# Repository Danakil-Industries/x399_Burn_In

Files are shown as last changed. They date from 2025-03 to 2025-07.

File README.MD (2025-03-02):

This project is about developing a low cost burn-in station for LM399s and ADR1399s in TO-46 packages.

Goals:
	1. Reference-supply rails seperate from, or at least derived from, heater supply rail.
	2. Able to burn-in at least 4 Vrefs simultaneously per unit
	3. All components at least 0603 or larger for ease of assembly
		*Preferrably 0805 or larger
	4. Socketed Vrefs
		*Probably use 2mm 2x2 F headers.
	5. Low cost
		*Possibly have multiple variants, enabling people to not need to spend more on functions they might not want to spend money on
			*Make bare-bones design
	Optional 1 (abandoned): Have a resettable hour meter to keep track of how long the Vrefs have been burning in for
								*Would have increased cost too much. Maybe make as an accessory for the unit?
	Optional 2: Have LEDs for indicating that the heater and +15v rail are alive
	Optional 3: Hot-swapable X399s
					*Alternatively, have a way to safely load a Vref without powering down the whole unit
					*Might end up being too expensive
	Optional 4: LEDs showing if the voltage seen at the X399's Vref+ pin is too high(>≈7.5v), fine(≈7.5v>Vref>≈6.5v), or too low(<≈6.5v)
					*Yes, this range is WAY over the tolerances of the Vrefs. It is meant to indicate if something has gone seriously wrong.
	Optional 5: If Vref+ voltage is too high, shut down the current supply, go into an error state, and light an error LED.

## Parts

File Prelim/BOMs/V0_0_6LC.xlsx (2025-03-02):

X399 Burn In V0.0.6LC
 | WIP |  |  |  | $21.58
 | index | Designator | Value | PN | Cost | Comment | To Add?
 | 1 | AC-DC1 | 18V18W wall wart | 1939-2007-ND | $6.50 | Barrel Plug, 2.5mm I.D. x 5.5mm O.D. x 11.0mm | Y
 | 2 | J1 |  |  |  |  | Y
 | 3 | F1 | 1AF63V | C1F 1 | $0.34 | 1206 package | Y
 | 4 | VR1 | 18v varistor | BVR0805-14PFR | $0.40 |  | Y
 | 5 | D1 | 40V 2A schottky | SS2040LL_R1_00001 | $0.15 |  | Y
 | 6 | FB1 | 600Ω@100MHz | 2508056017Y2 | $0.10 |  | Y
 | 7 | C1 | 100nF 50V | CL31B104KBCNNNC | $0.10 | 1206 | N
 | 8 | C2 | 10uF 25V | CL31A106KAHNNNE | $0.15 | 1206 | N
 | 9 | DC-DC1 | 3.3v 500mA | R-78E3.3-0.5 | $3.30 |  | Y
 | 10 | L1 | 12uH 58mΩ 2.2A | ASPI-6045S-120M-T | $0.39 |  | Y
 | 11 | C3 | 10uF 25V | CL31A106KAHNNNE | $0.15 |  | N
 | 12 | C4 | 4.7uF | CL31B475KAHNNNE | $0.15 |  | Y
 | 13 | C5 | DNP | DNP | $0.00 | DNP
 | 14 | R1 | 1k | RMCF1206FT1K00 | $0.10 |  | N
 | 15 | C6 | 1uF 50v | CL21F105ZBFNNNG | $0.10 |  | N
 | 16 | U1 | Quad Op Amp | LM324ADR | $0.26 |  | Y
 | 17 | U2 | 78L15 | L78L15ACD13TR | $0.25 | 8-SOIC pkg | Y
 | 18 | C7 | 100nF 50V | CL31B104KBCNNNC | $0.10 |  | N
 | 19 | SW1 | Push Switch DPDT | MHPS2273 | $0.74 |  | Y
 | 20 | SW2 | Push Switch DPDT | MHPS2273 | $0.74 |  | Y
 | 21 | SW3 | Push Switch DPDT | MHPS2273 | $0.74 |  | Y
 | 22 | SW4 | Push Switch DPDT | MHPS2273 | $0.74 |  | Y
 | 23 | SW5 | Push Switch DPDT | MHPS2273 | $0.74 |  | Y
 | 24 | Q1 | 2222 | MMBT2222A-TP | $0.11 |  | Y
 | 25 | D2 | Green LED | 151031VS06000 | $0.15 |  | N
 | 26 | D3 | Green LED | 151031VS06000 | $0.15 |  | N
 | 27 | D4 | Green LED | 151031VS06000 | $0.15 |  | N
 | 28 | D5 | Green LED | 151031VS06000 | $0.15 |  | N
 | 29 | D6 | Green LED | 151031VS06000 | $0.15 |  | N
 | 30 | R2 | 100Ω 1% 1206 | RMCF1206FT100R | $0.10 |  | N
 | 31 | R3 | 100Ω 1% 1206 | RMCF1206FT100R | $0.10 |  | N
 | 32 | R4 | 100Ω 1% 1206 | RMCF1206FT100R | $0.10 |  | N
 | 33 | R5 | 100Ω 1% 1206 | RMCF1206FT100R | $0.10 |  | N
 | 34 | R6 | 100Ω 1% 1206 | RMCF1206FT100R | $0.10 |  | N
 | 35 | R7 | 100Ω 1% 1206 | RMCF1206FT100R | $0.10 |  | N
 | 36 | D7 | Dual Schottky | BAS40-05,215 | $0.10 | SOT-23 | Y
 | 37 | D8 | Dual Schottky | BAS40-05,215 | $0.10 | SOT-23 | Y
 | 38 | D9 | Dual Schottky | BAS40-05,215 | $0.10 | SOT-23 | Y
 | 39 | D10 | Dual Schottky | BAS40-05,215 | $0.10 | SOT-23 | Y
 | 40 | RN1 | 1k 1% 4 Element | CAY16-1001F4LF | $0.10 | 1206 | Y
 | 41 | RN2 | 1k 1% 4 Element | CAY16-1001F4LF | $0.10 | 1206 | Y
 | 42 | RN3 | 1k 1% 4 Element | CAY16-1001F4LF | $0.10 | 1206 | Y
 | 43 | RN4 | 1k 1% 4 Element | CAY16-1001F4LF | $0.10 | 1206 | Y
 | 44 | C8 | 1uF 50v | CL21F105ZBFNNNG | $0.10 |  | N
 | 45 | C9 | 1uF 50v | CL21F105ZBFNNNG | $0.10 |  | N
 | 46 | C10 | 1uF 50v | CL21F105ZBFNNNG | $0.10 |  | N
 | 47 | C11 | 1uF 50v | CL21F105ZBFNNNG | $0.10 |  | N
 | 48 | J2 | 2x2 2mm F Hdr | S5750-02-ND | $0.67 |  | Y
 | 49 | J3 | 2x2 2mm F Hdr | S5750-02-ND | $0.67 |  | Y
 | 50 | J4 | 2x2 2mm F Hdr | S5750-02-ND | $0.67 |  | Y
 | 51 | J5 | 2x2 2mm F Hdr | S5750-02-ND | $0.67 |  | Y

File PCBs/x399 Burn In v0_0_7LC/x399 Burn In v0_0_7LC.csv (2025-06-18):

Source: | E:\Github\x399 Burn In\x399_Burn_In\PCBs\x399 Burn In v0_0_7LC\x399 Burn In v0_0_7LC.kicad_sch
Date: | 6/16/2025 7:44:11 PM
Tool: | Eeschema 7.0.10
Generator: | E:\KICad\7.0\bin\scripting\plugins/bom_csv_grouped_by_value.py
Component Count: | 57
Collated Components:
Item | Qty | Reference(s) | Value | LibPart | Footprint | Datasheet | DNP | Breaking Capacity (A AC) | Breaking Capacity (A DC) | Color | Comment | Current (A) | Current Rating (A) | DCR | DCR (max) | Diameter | Distributor | Distributor PN | Drive Type | Energy (J) | For | Gain | Has Hole | Head Type | Height | I (max) | ID | Ic | If (mA) | Imax | Imax (DC) | Iout | Iout Max | MFG | MFG PN | Matching Ratio | Material | Mating Connector PN | Max ACV | Max DCV | Max Voltage | Melting I2T | Min ESR(mΩ) | Mounting Type | Name | Number of elements | OD | Pmax | Power | Power / element (mW) | Ratio Drift (PPM/°C) | Response Time | Schematic Only | Sim.Device | Sim.Pins | Sim.Type | Size | Surge Current (A) | Symbol
1 | 1 | AC-DC1 | 18V 1A 18W | Danakil_database:PSUs - Wall Wart/18V 1A 18W Wall Wart | Connectors:CUI_PJ-002B | https://globtek.secure.force.com/spec/?id=01t0c0000097CKB |  |  |  |  |  | 1 |  |  |  |  | Digikey | 1939-2007-ND |  |  |  |  |  |  |  |  |  |  |  |  |  |  |  | GlobTek, Inc. | WR9HH1000LCP-F(R6B) |  |  | PJ-002B |  |  |  |  |  |  | 18V 1A 18W Wall Wart |  |  |  |  |  |  |  |  |  |  |  |  |  | 0Dan_PSUs_WallWarts:WR9HH1000LCP-F(R6B)
2 | 2 | C1, C3 | 10u | Danakil_database:Capacitors - Unpolarized/10uF 25V 1206 X5R SMD MLCC | Capacitors_SMD:C_1206_3216Metric | https://mm.digikey.com/Volume0/opasdata/d220001/medias/docus/609/CL31A106KAHNNNE_SS.pdf |  |  |  |  |  |  |  |  |  |  | Digikey | 1276-1075-1-ND |  |  |  |  |  |  |  |  |  |  |  |  |  |  |  | Samsung Electro-Mechanics | CL31A106KAHNNNE |  |  |  |  |  |  |  |  | SMD | 10uF 25V 1206 X5R SMD MLCC |  |  |  |  |  |  |  |  |  |  |  | 1206 |  | 0Dan_Passives:C
3 | 2 | C2, C7 | 100n | Danakil_database:Capacitors - Unpolarized/100nF 50V 1206 X7R SMD MLCC | Capacitors_SMD:C_1206_3216Metric | https://mm.digikey.com/Volume0/opasdata/d220001/medias/docus/1256/CL31B104KBCNNNC_Spec.pdf |  |  |  |  |  |  |  |  |  |  | Digikey | 1276-1017-1-ND |  |  |  |  |  |  |  |  |  |  |  |  |  |  |  | Samsung Electro-Mechanics | CL31B104KBCNNNC |  |  |  |  |  |  |  |  | SMD | 100nF 50V 1206 X7R SMD MLCC |  |  |  |  |  |  |  |  |  |  |  | 1206 |  | 0Dan_Passives:C
4 | 2 | C4, C5 | 4.7u | Danakil_database:Capacitors - Unpolarized/4.7uF 25V 1206 X7R SMD MLCC | Capacitors_SMD:C_1206_3216Metric | https://mm.digikey.com/Volume0/opasdata/d220001/medias/docus/41/CL31B475KAHNNNE_Spec.pdf |  |  |  |  |  |  |  |  |  |  | Digikey | 1276-1055-1-ND |  |  |  |  |  |  |  |  |  |  |  |  |  |  |  | Samsung Electro-Mechanics | CL31B475KAHNNNE |  |  |  |  |  |  |  |  | SMD | 4.7uF 25V 1206 X7R SMD MLCC |  |  |  |  |  |  |  |  |  |  |  | 1206 |  | 0Dan_Passives:C
5 | 5 | C6, C8, C9, C10, C11 | 1u | Danakil_database:Capacitors - Unpolarized/1uF 50V 0805 Y5V SMD MLCC | Capacitors_SMD:C_0805_2012Metric | https://weblib.samsungsem.com/mlcc/mlcc-ec-data-sheet.do?partNumber=CL05Y105KP6VPN |  |  |  |  |  |  |  |  |  |  | Digikey | 1276-6495-1-ND |  |  |  |  |  |  |  |  |  |  |  |  |  |  |  | Samsung Electro-Mechanics | CL21F105ZBFNNNG |  |  |  |  |  |  |  |  | SMD | 1uF 50V 0805 Y5V SMD MLCC |  |  |  |  |  |  |  |  |  |  |  | 0805 |  | 0Dan_Passives:C
6 | 1 | D1 | Schottky 40V 2A SMD | Danakil_database:Discreet - Diodes - Schottky/Schottky 40V 2A SMD | Diodes:D_SOD-123F | https://www.panjit.com.tw/upload/datasheet/SS2040LL.pdf |  |  |  |  |  |  |  |  |  |  | Digikey | 3757-SS2040LL_R1_00001CT-ND |  |  |  |  |  |  |  | 2A |  |  |  |  |  |  |  | Panjit International Inc. | SS2040LL_R1_00001 |  |  |  |  |  |  |  |  | SMD | Schottky 40V 2A SMD |  |  |  |  |  |  |  |  |  | 1=K 2=A |  |  |  | 0Dan_Discreet:Diode_Schottky
7 | 5 | D2, D3, D4, D5, D6 | Green 3mm | Danakil_database:LEDs - Standard - Indicator - Through Hole/Green 3mm 560nm 2.2v 20mA | Discreet_TH:LED_3mm_wurth | https://www.we-online.com/components/products/datasheet/151031VS06000.pdf |  |  |  | Green |  |  |  |  |  |  | Digikey | 732-5008-ND |  |  |  |  |  |  |  |  |  |  | 20 |  |  |  |  | Würth Elektronik | 151031VS06000 |  |  |  |  |  |  |  |  |  | Green 3mm 560nm 2.2v 20mA |  |  |  |  |  |  |  |  |  |  |  | 3mm |  | 0Dan_Discreet:LED
8 | 4 | D7, D8, D9, D10 | Schottky 40V 0.12A SMD | Danakil_database:Discreet - Diodes - Schottky/Schottky 40V 0.12A SMD Dual CC | Discreet_SMD:SOT-23-3_1 | https://assets.nexperia.com/documents/data-sheet/BAS40-05.pdf |  |  |  |  | Dual CC |  |  |  |  |  | Digikey | 1727-4235-1-ND |  |  |  |  |  |  |  | 0.12A |  |  |  |  |  |  |  | Nexperia USA Inc. | BAS40-05,215 |  |  |  |  |  |  |  |  | SMD | Schottky 40V 0.12A SMD Dual CC |  |  |  |  |  |  |  |  |  |  |  |  |  | 0Dan_Discreet:Diode_Schottky_BAS40-05
9 | 1 | DC-DC1 | 5v 0.5A Buck | Danakil_database:PSUs - PCB Mount - DC-DC - Non-Isolated/Buck 7v-28v to 5v0.5A | DCDC_NonIso:R-78E-0.5 | https://recom-power.com/pdf/Innoline/R-78E-0.5.pdf |  |  |  |  |  |  |  |  |  |  | Digikey | 945-1648-5-ND |  |  |  |  |  |  |  |  |  |  |  |  |  | 0.5A |  | Recom Power | R-78E5.0-0.5 |  |  |  |  |  |  |  |  |  | Buck 7v-28v to 5v0.5A |  |  |  |  |  |  |  |  |  |  |  |  |  | 0Dan_PSUs:78xx Replacement
10 | 1 | F1 | 125VAC/63VDC 1A F | Danakil_database:Protection - Fuses/125VAC/63VDC 1A F SMD | Protection_Fuses:Fuse_1206 | https://www.belfuse.com/resources/datasheets/circuitprotection/ds-cp-c1f-series.pdf |  | 100 | 50 |  |  |  | 1 |  |  |  | Digikey | 5923-C1F1CT-ND |  |  |  |  |  |  |  |  |  |  |  |  |  |  |  | Bel Fuse Inc. | C1F 1 |  |  |  |  |  |  | 0.012 |  | SMD | 125VAC/63VDC 1A F SMD |  |  |  |  |  |  | F |  |  |  |  |  |  | 0Dan_Protection:Fuse
11 | 1 | FB1 | 600Ω@100MHz 0.1ΩDCR | Danakil_database:Inductors - Ferrite Bead/600Ω@100MHz 2A 0.1ΩDCR | Inductors_SMD:L_0805_2012Metric | https://fair-rite.com/product/chip-beads-2508056017y2/ |  |  |  |  |  |  |  |  | 0.1Ω |  | Digikey | 1934-1487-1-ND |  |  |  |  |  |  |  |  |  |  |  | 2A |  |  |  | Fair-Rite Products Corp. | 2508056017Y2 |  |  |  |  |  |  |  |  |  | 600Ω@100MHz 2A 0.1ΩDCR |  |  |  |  |  |  |  |  |  |  |  |  |  | 0Dan_Passives:FB
12 | 1 | J1 | 2.5mmID 5.5mmOD | Danakil_database:Connectors - Barrel Jack/2.5mmID 5.5mmOD | Connectors:CUI_PJ-002B | https://www.sameskydevices.com/product/resource/pj-002b.pdf |  |  |  |  |  |  |  |  |  |  | Digikey | CP-002B-ND |  |  |  |  |  |  |  |  | 2.5mm |  |  |  |  |  |  | Same Sky (Formerly CUI Devices) | PJ-002B |  |  |  |  |  |  |  |  |  | 2.5mmID 5.5mmOD |  | 5.5mm |  |  |  |  |  |  |  |  |  |  |  | 0Dan_Connectors:Barrel_Jack_Switch
13 | 1 | L1 | 12u | Danakil_database:Inductors/12uH 2.2A 58mΩ 20% NonStd SMD | Inductors_SMD:ASPI-6045S-120M-T | https://abracon.com/Magnetics/power/ASPI-6045S.pdf |  |  |  |  |  |  |  | 58m |  |  | Digikey | 535-ASPI-6045S-120M-TCT-ND |  |  |  |  |  |  |  |  |  |  |  |  |  |  |  | Abracon LLC | ASPI-6045S-120M-T |  |  |  |  |  |  |  |  | SMD | 12uH 2.2A 58mΩ 20% NonStd SMD |  |  |  |  |  |  |  |  |  |  |  | NonStd |  | 0Dan_Passives:L
14 | 1 | M1 | M3x0.5 0.3mm_tall | Danakil_database:Mechanical - Standoffs - SMD/M3x0.5 0.3mm_tall Elect_Conn | Mechanical_Standoffs_SMD:24939_ElecConn | https://www.keyelco.com/product-pdf.cfm?p=14826 |  |  |  |  | Elect_Conn |  |  |  |  |  | Digikey | 36-24939CT-ND |  |  |  |  |  |  | 0.3mm |  |  |  |  |  |  |  |  | Keystone Electronics | 24939 |  |  |  |  |  |  |  |  |  | M3x0.5 0.3mm_tall Elect_Conn |  |  |  |  |  |  |  |  |  |  |  |  |  | 0Dan_Mech_Standoffs:SMD_ElecConn
15 | 4 | M2, M3, M4, M5 | 9.5mm Black | Danakil_database:Mechanical - Feet/9.5mm_dia 5.4mm_height Black | Feet:BS22BL05X06RP | https://mm.digikey.com/Volume0/opasdata/d220001/medias/docus/699/Bumper_Brochure.pdf |  |  |  | Black |  |  |  |  |  | 9.5mm | Digikey | 2042-1050-ND |  |  |  |  |  |  | 5.4mm |  |  |  |  |  |  |  |  | Bumper Specialties Inc. | BS22BL05X06RP |  |  |  |  |  |  |  |  |  | 9.5mm_dia 5.4mm_height Black |  |  |  |  |  |  |  |  |  |  |  |  |  | 0Dan_Mech_Feet:Foot
16 | 1 | Q1 | 2222A | Danakil_database:Discreet - Transistors - BJT - NPN/2222A 40V-Vce 0.6A-Ic 0.35W 100-Bmin SMD | Discreet_SMD:SOT-23-3 | https://www.mccsemi.com/pdf/Products/MMBT2222A(SOT-23).pdf |  |  |  |  |  |  |  |  |  |  | Digikey | MMBT2222ATPMSCT-ND |  |  |  | 100 |  |  |  |  |  | 0.6A |  |  |  |  |  | MCC (Micro Commercial Components) | MMBT2222A-TP |  |  |  |  |  |  |  |  | SMD | 2222A 40V-Vce 0.6A-Ic 0.35W 100-Bmin SMD |  |  | 0.35W |  |  |  |  |  | NPN | 1=C 2=B 3=E | GUMMELPOON |  |  | 0Dan_Discreet:NPN
17 | 1 | R1 | 1k | Danakil_database:Resistors - Single - SMD/1kΩ 1% 1206 0.25w Thick Film 200ppm/°C Automotive | Resistors_SMD:R_1206_3216Metric | https://www.seielect.com/catalog/sei-rmcf_rmcp.pdf |  |  |  |  | Automotive |  |  |  |  |  | Digikey | RMCF1206FT1K00CT-ND |  |  |  |  |  |  |  |  |  |  |  |  |  |  |  | Stackpole Electronics Inc | RMCF1206FT1K00 |  |  |  |  |  |  |  |  |  | 1kΩ 1% 1206 0.25w Thick Film 200ppm/°C Automotive |  |  |  | 0.25 |  |  |  |  |  |  |  | 1206 |  | 0Dan_Passives:R_US
18 | 1 | R2 | 47k | Danakil_database:Resistors - Single - SMD/47kΩ 1% 1206 0.25w Thick Film 100ppm/°C Automotive | Resistors_SMD:R_1206_3216Metric | https://www.seielect.com/catalog/sei-rmcf_rmcp.pdf |  |  |  |  | Automotive |  |  |  |  |  | Digikey | RMCF1206FT47K0CT-ND |  |  |  |  |  |  |  |  |  |  |  |  |  |  |  | Stackpole Electronics Inc | RMCF1206FT47K0 |  |  |  |  |  |  |  |  |  | 47kΩ 1% 1206 0.25w Thick Film 100ppm/°C Automotive |  |  |  | 0.25 |  |  |  |  |  |  |  | 1206 |  | 0Dan_Passives:R_US
19 | 5 | R3, R4, R5, R6, R7 | 330 | Danakil_database:Resistors - Single - SMD/330Ω 1% 1206 0.25w Thick Film 100ppm/°C Automotive | Resistors_SMD:R_1206_3216Metric | https://www.seielect.com/catalog/sei-rmcf_rmcp.pdf |  |  |  |  | Automotive |  |  |  |  |  | Digikey | RMCF1206FT330RCT-ND |  |  |  |  |  |  |  |  |  |  |  |  |  |  |  | Stackpole Electronics Inc | RMCF1206FT330R |  |  |  |  |  |  |  |  |  | 330Ω 1% 1206 0.25w Thick Film 100ppm/°C Automotive |  |  |  | 0.25 |  |  |  |  |  |  |  | 1206 |  | 0Dan_Passives:R_US
20 | 4 | RN1, RN2, RN3, RN4 | 1k | Danakil_database:Resistors - Isolated Array/1kΩ 1% 4-Element 1206 62.5mW 50V Thick Film 200PPM/°C | Resistors_SMD_Networks:BO_CAY16 | https://www.bourns.com/docs/Product-Datasheets/CATCAY.pdf |  |  |  |  |  |  |  |  |  |  | Digikey | CAY16-1001F4LFCT-ND |  |  |  |  |  |  |  |  |  |  |  |  |  |  |  | Bourns Inc. | CAY16-1001F4LF |  |  |  |  |  | 50 |  |  |  | 1kΩ 1% 4-Element 1206 62.5mW 50V Thick Film 200PPM/°C | 4 |  |  |  | 62.5 |  |  |  |  |  |  | 1206 |  | 0Dan_Passives:R_Network04_Iso
21 | 1 | RV1 | 14VAC/18VDC | Danakil_database:Protection - MOVs/14VAC/18VDC 120A J SMD | Protection_MOV:MOV_0805 | https://www.bourns.com/docs/Product-Datasheets/BVR0805.pdf |  |  |  |  |  |  |  |  |  |  | Digikey | 118-BVR0805-14PFRCT-ND |  |  |  |  |  |  |  |  |  |  |  |  |  |  |  | Bourns Inc. | BVR0805-14PFR |  |  |  | 14 | 18 |  |  |  | SMD | 14VAC/18VDC 120A J SMD |  |  |  |  |  |  |  |  |  |  |  |  | 120 | 0Dan_Protection:MOV
22 | 1 | Screw 1 | M3x0.5x6 Binding Head Green | Danakil_database:Mechanical - Screws/M3x0.5x6 Combination Drive Binding Head Brass Green | Screws:9191 | https://www.keyelco.com/product-pdf.cfm?p=1928 |  |  |  |  | Green |  |  |  |  |  | Digikey | 36-9191-6-ND | Combination |  |  |  | FALSE | Binding Head |  |  |  |  |  |  |  |  |  | Keystone Electronics | 9191-6 |  | Brass |  |  |  |  |  |  |  | M3x0.5x6 Combination Drive Binding Head Brass Green |  |  |  |  |  |  |  | FALSE |  |  |  | M3x0.5x6 |  | 0Dan_Mech_Screws:M3-6mm_Pan_Green
23 | 5 | SW1, SW2, SW3, SW4, SW5 | Push 30V 0.1A | Danakil_database:Switches - Push/DPDT Push 30V 0.1A | Switches_Push:SW_TL2230EEF100 | https://configured-product-images.s3.amazonaws.com/Datasheets/TL2230.pdf |  |  |  |  | Latching |  |  |  |  |  | Digikey | E-Switch |  |  |  |  |  |  |  |  |  |  |  |  | 0.1A |  |  | E-Switch | TL2230EEF100 |  |  |  |  |  |  |  |  |  | DPDT Push 30V 0.1A |  |  |  |  |  |  |  |  |  |  |  |  |  | 0Dan_Switches:Push_DPDT_Latching
24 | 1 | U1 | LM324 | Danakil_database:ICs - Analog - OP Amp/LM324 | ICs:SOIC-14_3.9x8.7mm_P1.27mm | https://www.ti.com/lit/ds/symlink/lm224.pdf?HQS=dis-dk-null-digikeymode-dsf-pf-null-wwe&ts=1741206371483 |  |  |  |  |  |  |  |  |  |  | Digikey | 296-9540-1-ND |  |  |  |  |  |  |  |  |  |  |  |  |  |  |  | Texas Instruments | LM324ADR |  |  |  |  |  |  |  |  |  | LM324 |  |  |  |  |  |  |  |  |  |  |  |  |  | 0Dan_OpAmps:LM324
25 | 1 | U2 | 78L15 | Danakil_database:ICs - Power - Linear Regulation/78L15 Fixed 0.1A 1.7v@0.04A 35VinMax SMD | ICs:SOIC-8_3.9x4.9mm_P1.27mm | https://www.st.com/resource/en/datasheet/l78l.pdf |  |  |  |  |  |  |  |  |  |  | Digikey | 497-7278-1-ND |  |  |  |  |  |  |  |  |  |  |  |  |  |  | 0.1 | STMicroelectronics | L78L15ACD13TR |  |  |  |  |  |  |  | 0 | SMD | 78L15 Fixed 0.1A 1.7v@0.04A 35VinMax SMD |  |  |  |  |  |  |  |  |  |  |  |  |  | 0Dan_Linear_Regulation:78xx_1
26 | 4 | U3, U4, U5, U6 | x399 Vref Socket | Danakil_database:Connectors - IC socket/x399 Vref Socket | Connectors_ICskt:x399_Socket | https://drawings-pdf.s3.amazonaws.com/10497.pdf |  |  |  |  |  |  |  |  |  |  | Digikey | S5750-02-ND |  |  | x399 Vref |  |  |  |  |  |  |  |  |  |  |  |  | Sullins Connector Solutions | NPPN022AFCN-RC |  |  |  |  |  |  |  |  |  | x399 Vref Socket |  |  |  |  |  |  |  |  |  |  |  |  |  | 0Dan_VRefs-BZener:LM399
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

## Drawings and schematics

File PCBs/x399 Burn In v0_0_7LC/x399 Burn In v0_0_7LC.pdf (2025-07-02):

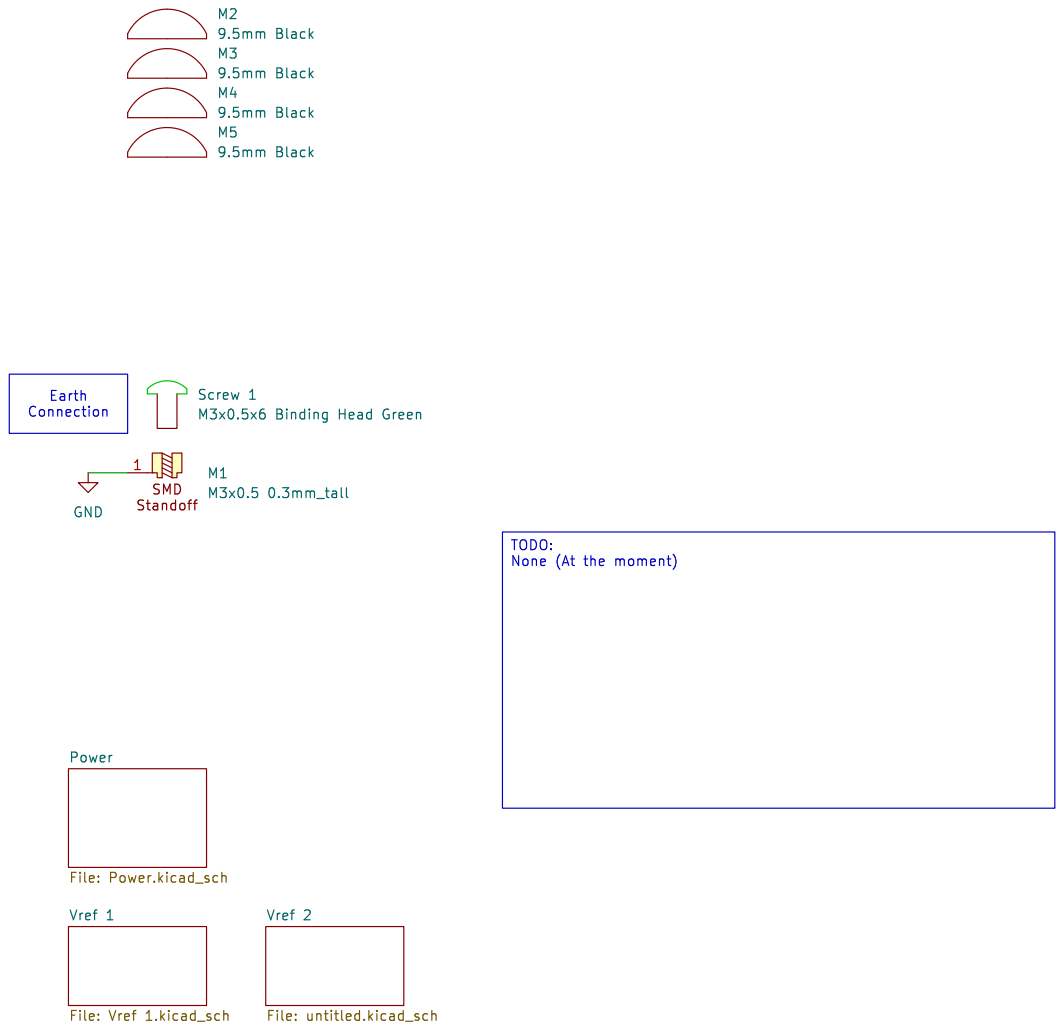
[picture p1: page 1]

9.5mm Black þÿScrew 1 M3x0.5x6 Binding Head Green M2

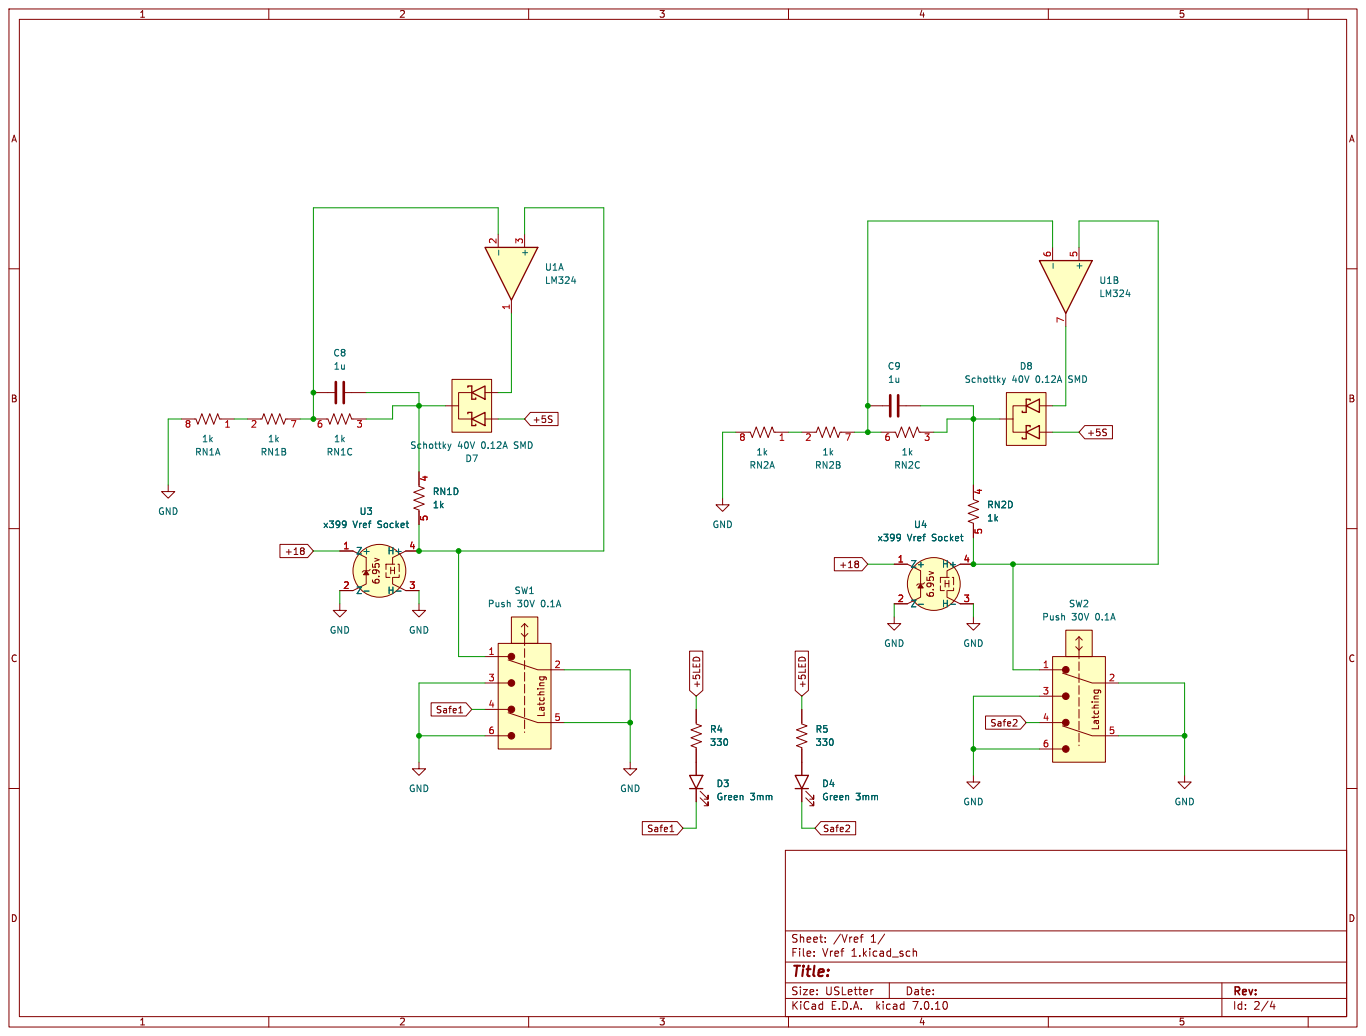
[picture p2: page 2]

Id: 2/4 Title: File: Vref 1.kicad_sch Sheet: /Vref 1/

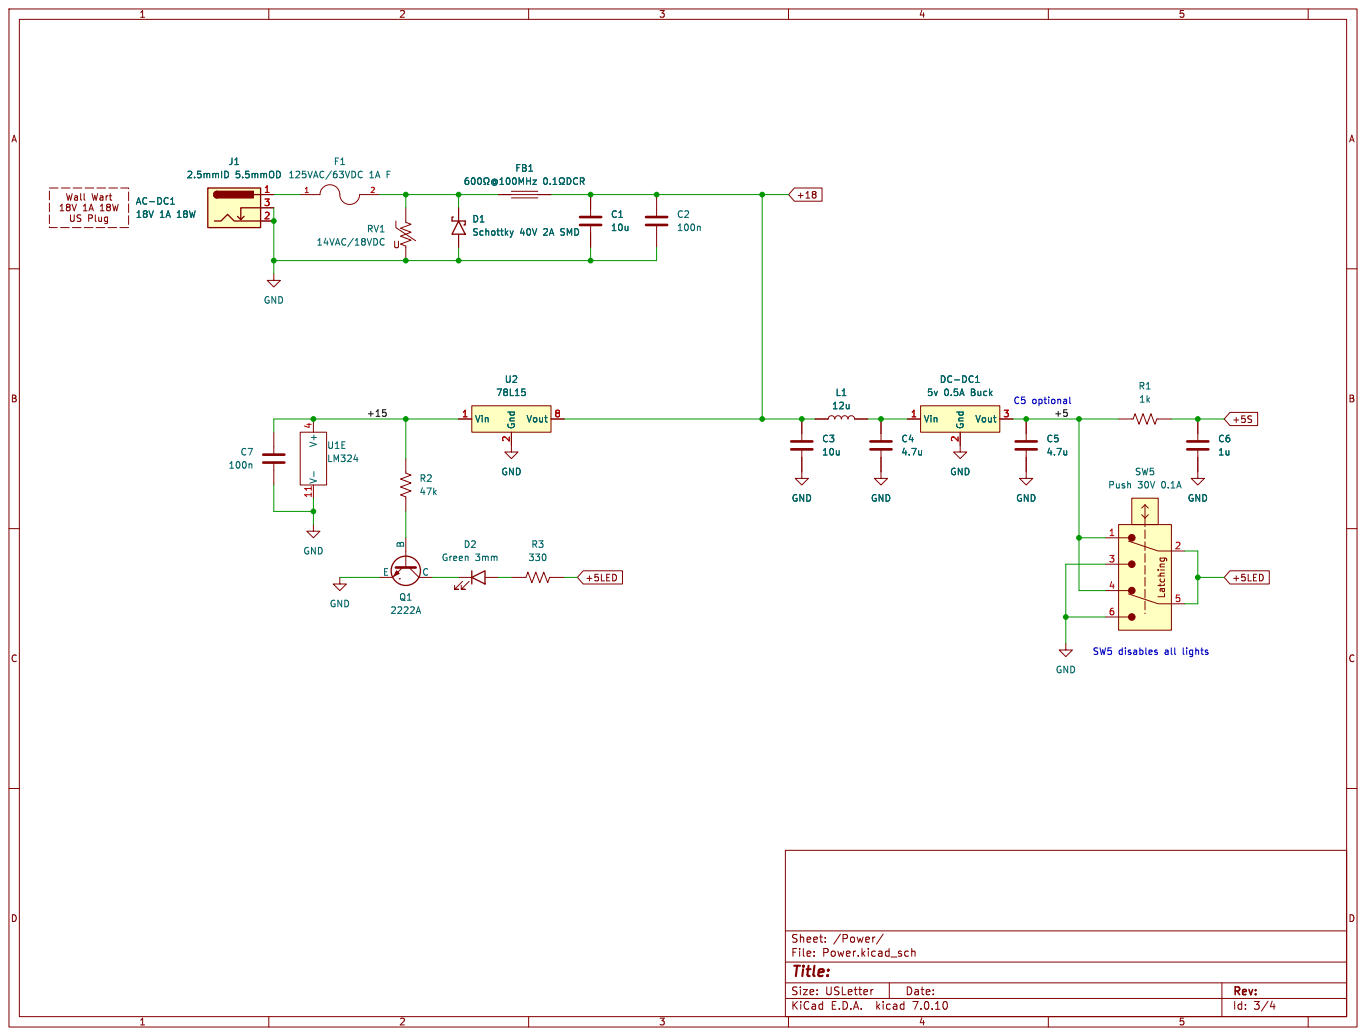
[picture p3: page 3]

Id: 3/4 Title: File: Power.kicad_sch Sheet: /Power/ R2

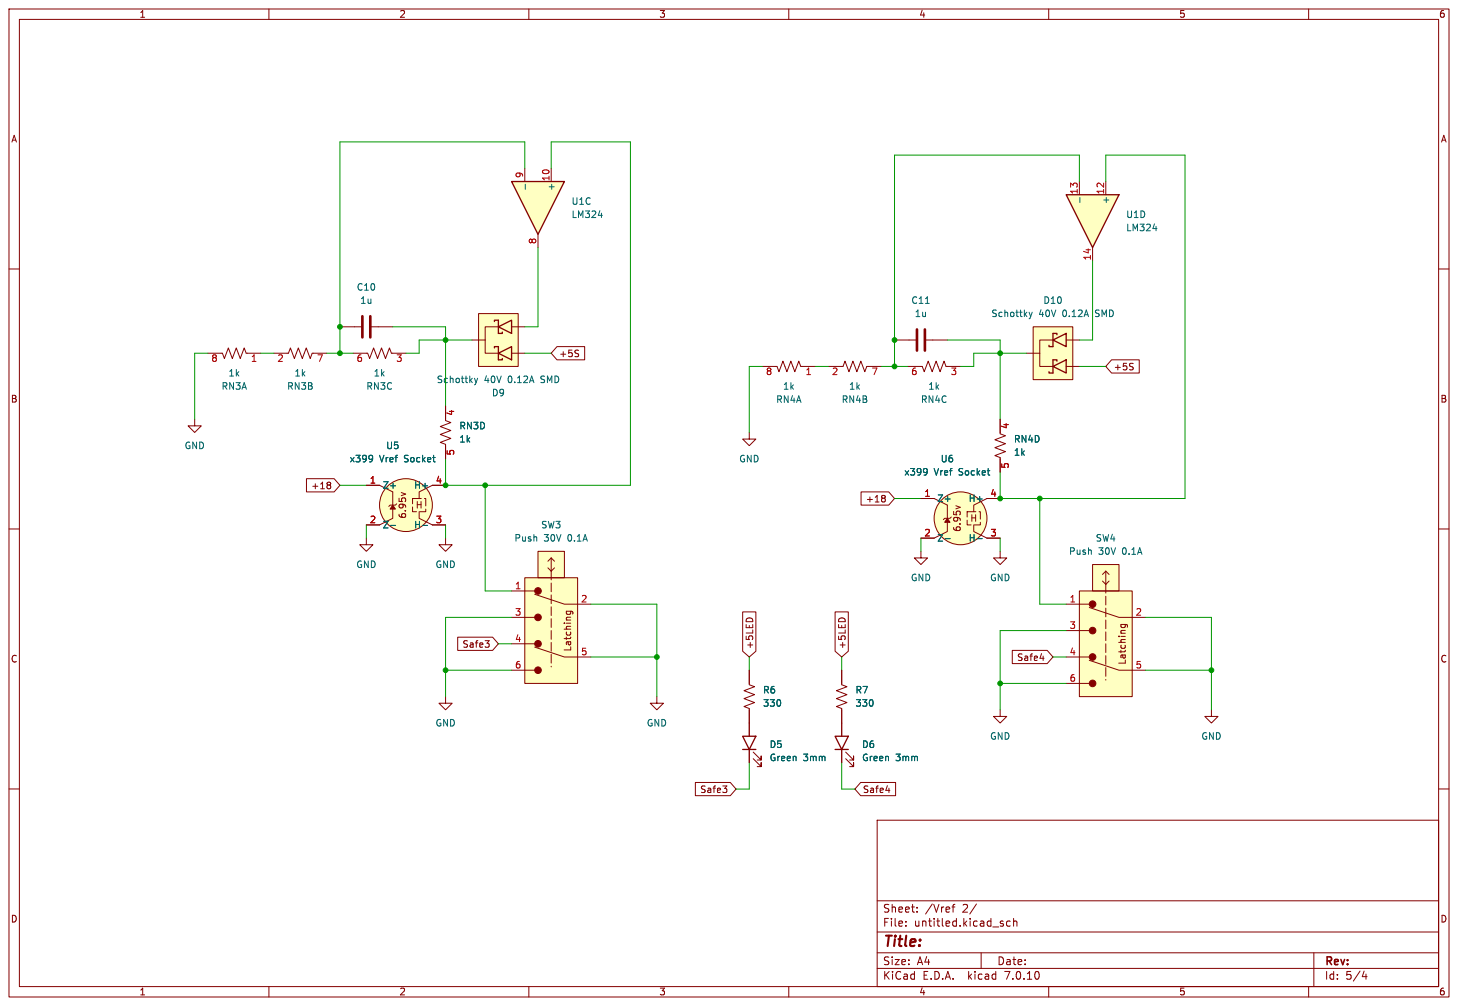
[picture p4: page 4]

Id: 5/4 Title: File: untitled.kicad_sch Sheet: /Vref 2/ R7

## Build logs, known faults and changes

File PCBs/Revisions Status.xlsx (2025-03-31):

Title | Status | Comment
x399 Burn In v0_0_6LC | In Progress | Prelim. First rev made on computer

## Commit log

2025-03-02 Changed Something
    [Calculations.xlsx, V0_0_6LC.xlsx]
2025-03-31 Initial Commit of PCB files
    [Calculations.xlsx, Indicators.kicad_sch, Power.kicad_sch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]
2025-06-18 Created gerbers for v0.0.6LC
    [x399 Burn In v0_0_6LC-B_Cu.gbr, x399 Burn In v0_0_6LC-B_Mask.gbr, x399 Burn In v0_0_6LC-B_Paste.gbr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]
2025-06-18 Initial commit of v0.0.7LC
    [Indicators.kicad_sch, Power.kicad_sch, Vref 1.kicad_sch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]
2025-07-02 Exported schematics as a PDF
2025-07-02 Do not make these
    For some reason, these are really putting the oven in ovenized burried zener diode. The testing ADR1399 is at 231°C for some reason.
